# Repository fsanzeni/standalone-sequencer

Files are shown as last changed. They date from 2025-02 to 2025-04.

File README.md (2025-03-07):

# Standalone Super Sixteen Sequencer

This repository contains a hardware project built in KiCad—a reimagined and streamlined version of the [Super Sixteen project](https://github.com/matthewcieplak/super-sixteen). The goal is to create a standalone sequencer suitable for Eurorack and other synthesizer setups.

## Project Overview

The original Super Sixteen design has been reworked into a modular, three-board system:
- **7 Segment Display Board:** Manages visual output.
- **DAC and Mono Jack Board:** Provides digital-to-analog conversion and audio interfacing.
- **16-Step Keyboard Board:** Features 16 Cherry MX switches paired with reverse-mount RGB LEDs for step sequencing.

> All pins are broken out for flexible connectivity. The boards are designed to work together or independently based on your setup.

## Key Modifications

- **Simplified Design:** Removed the IO expander from the original Super Sixteen to reduce complexity.
- **Modular Approach:** Each board can function as part of a larger system or as a standalone unit.
- **Fabrication Update:** The PCBs are currently in fabrication. This project is a work in progress (WIP).

## Getting Started

1. **Hardware Designs:** Navigate to the appropriate subfolder in the `hardware` directory to access the KiCad schematic and PCB layout files. There are four subfolders in here: three correspond to the three PCBs (i.e., the "keyboard", the DAC and IO board, the 3-digit 7-segment display driver). The fourth folder contains the keyboard layout files I generated with the [Keyboard Layout Editor](https://www.keyboard-layout-editor.com/), which I imported into Kicad with the excellent [kicad-kbplacer](https://github.com/adamws/kicad-kbplacer) plugin. You can use the JSON file provided in this folder to variate the switches' layout without having to go through the hassle of moving things around precisely on Kicad :).
2. **Software Development:** The `software` folder is currently empty. Firmware or control software will be added as the project develops.
3. **Documentation:** Detailed build instructions, assembly guides, and design notes will be provided in the `documentation` folder over time.

## Hardware Design
As mentioned above, ths repo contains three PCBs:

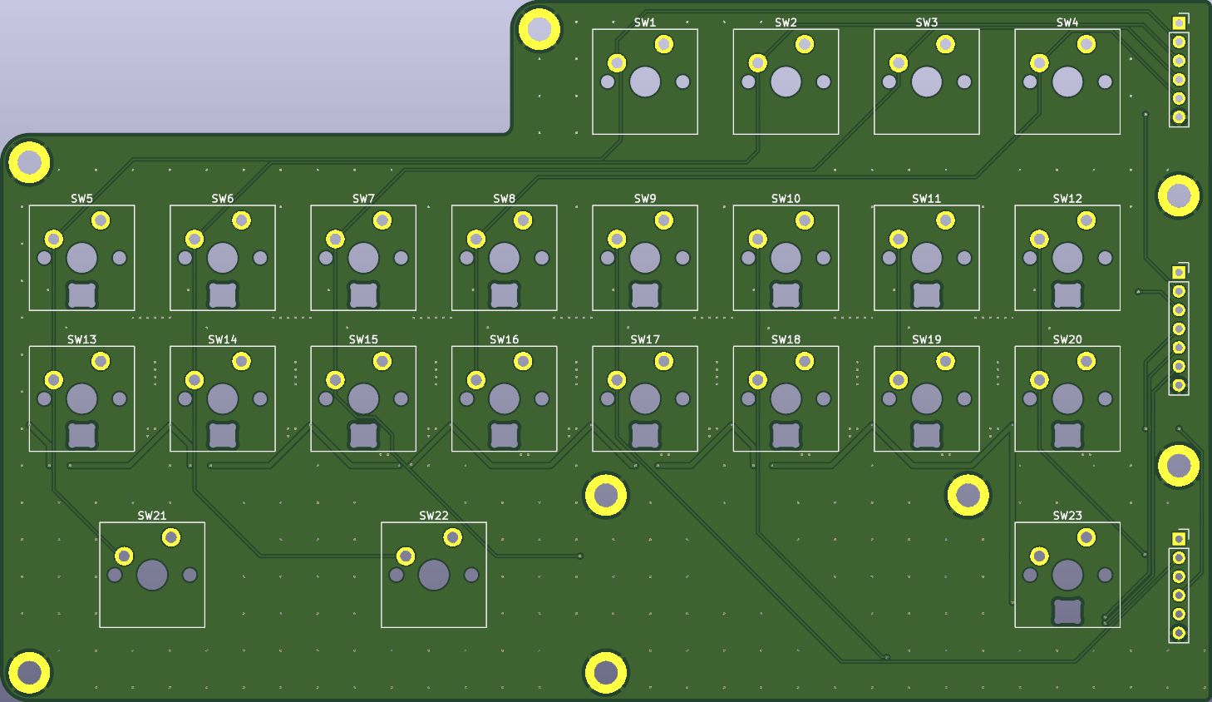
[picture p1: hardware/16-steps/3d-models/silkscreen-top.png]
16 steps pcb The keyboard PCB, with 16 steps and seven function buttons, all using Cherry MX keyswitches

_The keyboard PCB, with 16 steps and seven function buttons, all using Cherry MX keyswitches_

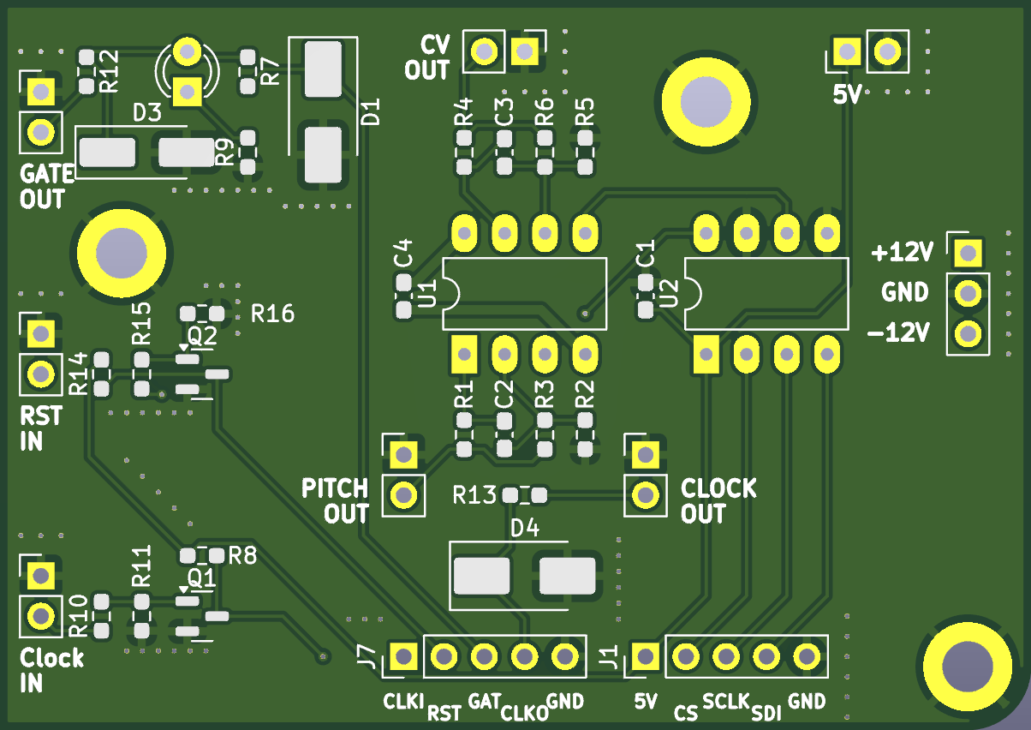
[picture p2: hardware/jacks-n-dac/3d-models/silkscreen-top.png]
DAC and Jacks pcb The DAC, opamp and IO board. I am using DIP packages for the two main ICs just because I had them laying around. The conversion to SMD packages is trivial - and there's plenty of space on the board!

_The DAC, opamp and IO board. I am using DIP packages for the two main ICs just because I had them laying around. The conversion to SMD packages is trivial - and there's plenty of space on the board!_

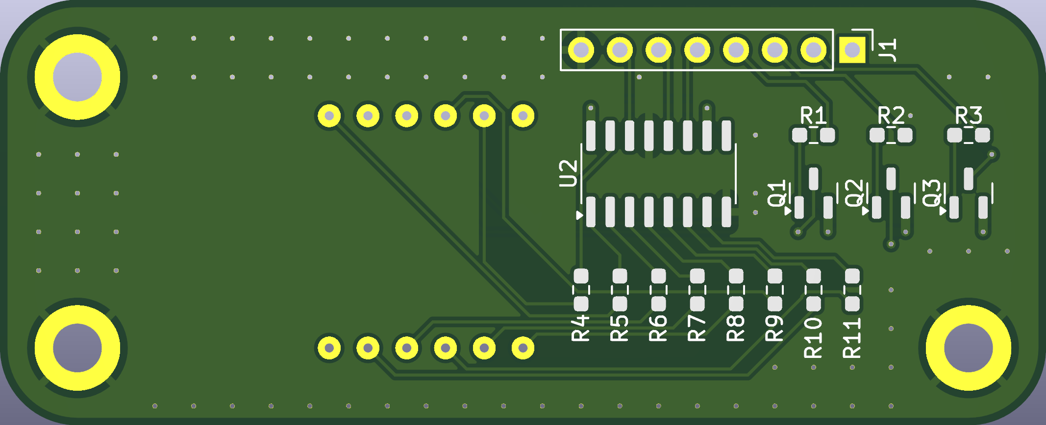
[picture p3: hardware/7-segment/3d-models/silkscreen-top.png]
7 Segment pcb The 7 segment driver pcb. I'm using a three-digit unit, 0.56in tall. Everything is driven by a 74HC595 to reduce the pins needed for interfacing with a microcontroller.

_The 7 segment driver pcb. I'm using a three-digit unit, 0.56" tall. Everything is driven by a 74HC595 to reduce the pins needed for interfacing with a microcontroller._

You will notice the glaring omission of a microcontroller from this setup. I am using the venerable Arduino MEGA as the brains of the operation, so that I have enough pins not to worry about faffing around with multiplexers and the like. 

## Inspiration

This project draws inspiration from the original [Super Sixteen project](https://github.com/matthewcieplak/super-sixteen). Visit their repository to learn more about the design and evolution of the sequencer.

## License

Code: GPL3.0 Hardware: cc-by-sa-3.0

## Contributing

Contributions, issues, and feature requests are welcome. Please feel free to open an issue or submit a pull request.

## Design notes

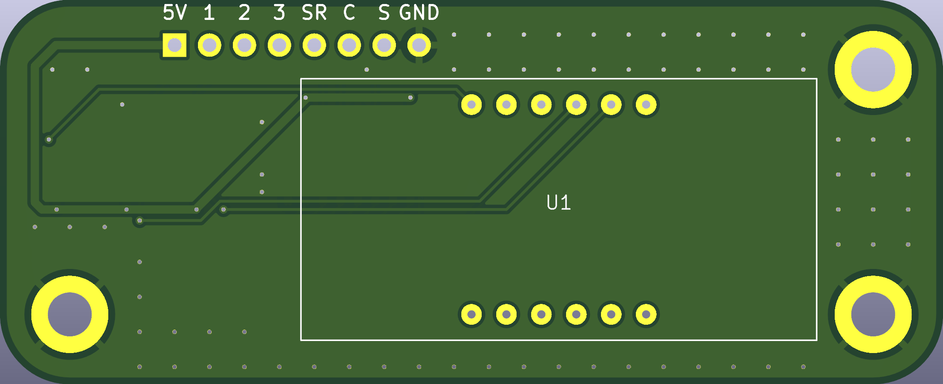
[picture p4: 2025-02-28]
hardware/7-segment/3d-models/silkscreen-bottom.png

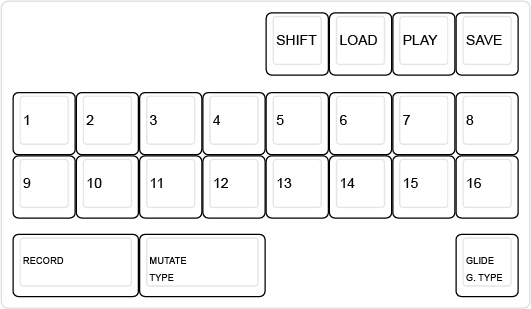
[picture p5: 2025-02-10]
hardware/switches layout/switches-layout.png

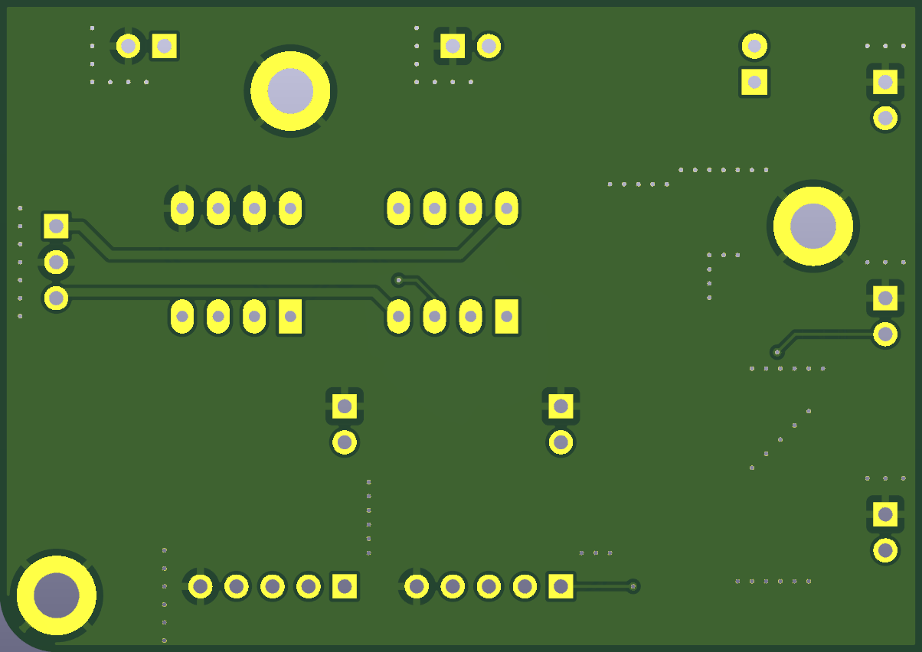
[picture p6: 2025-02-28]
hardware/jacks-n-dac/3d-models/silkscreen-bottom.png

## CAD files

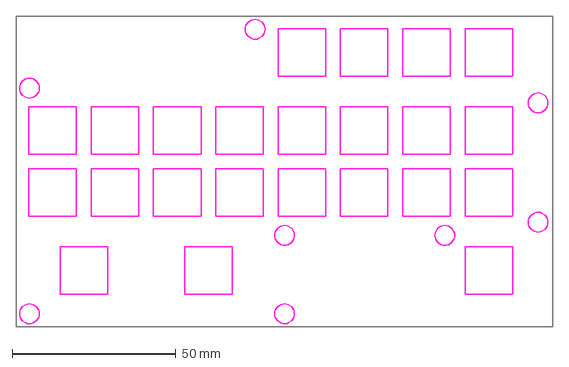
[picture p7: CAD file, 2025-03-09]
hardware/16-steps/16-steps-simplified-brd.dxf
164.0 x 95.0 mm

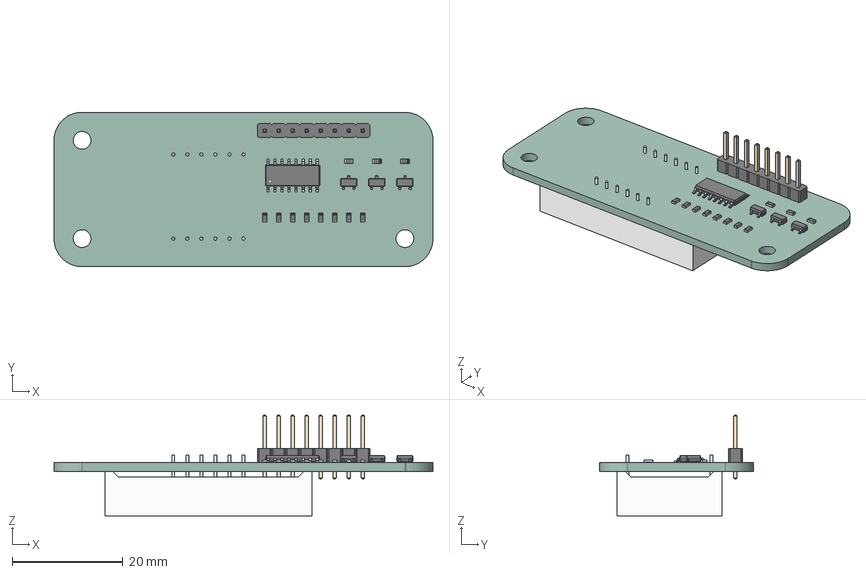
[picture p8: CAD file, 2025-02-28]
hardware/7-segment/3d-models/7-segment.step
68.6 x 27.9 x 18.2 mm
R_0603_1608Metric x 11
SOT_23 x 3
PinHeader_1x08_P254mm_Vertical
SOP-16_3.9x9.9mm_P1.27mm
(Unsaved)
7-segment_PCB

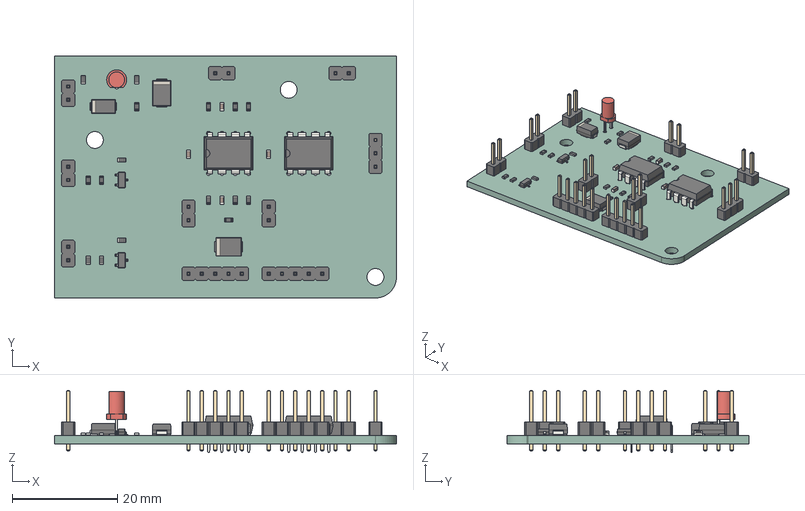
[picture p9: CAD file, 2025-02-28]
hardware/jacks-n-dac/3d-models/jacks-n-dac.step
65.0 x 46.0 x 11.8 mm
R_0603_1608Metric x 16
LED_D3.0mm_FlatTop
C_0603_1608Metric x 4
PinHeader_1x05_P254mm_Vertical x 2
DIP-8_W7.62mm x 2
PinHeader_1x02_P254mm_Vertical x 7
D_SMA
D_SMB x 2
PinHeader_1x03_P254mm_Vertical
SOT_23 x 2
jacks-n-dac_PCB

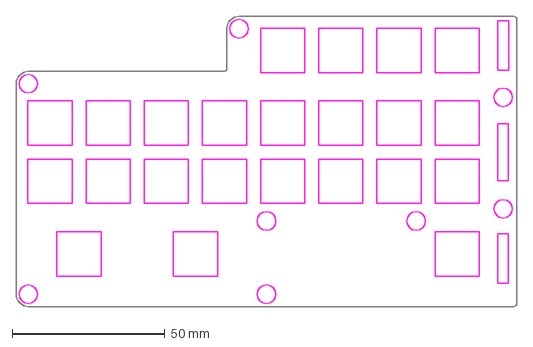
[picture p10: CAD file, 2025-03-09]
hardware/16-steps/16-steps-brd.dxf
164.0 x 95.0 mm

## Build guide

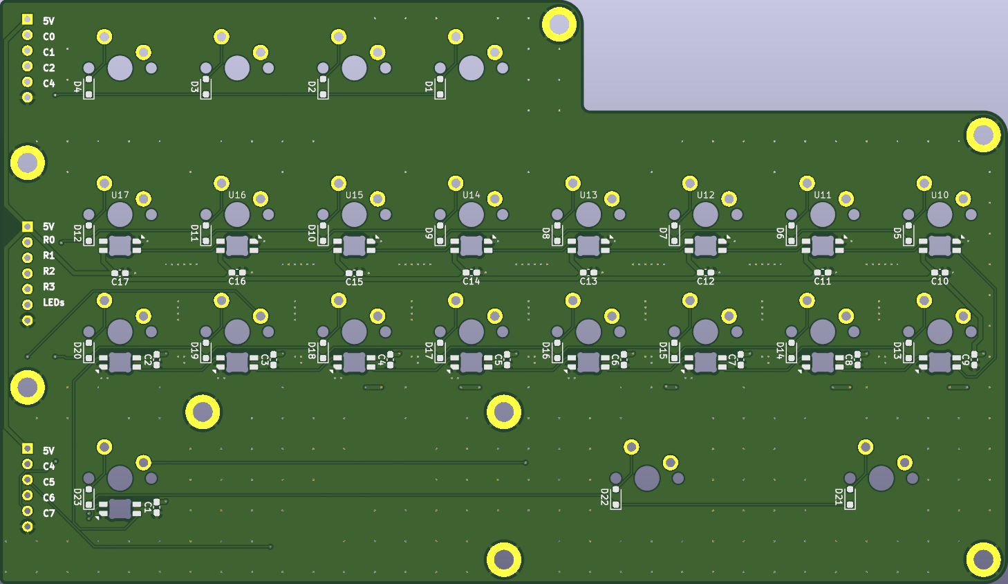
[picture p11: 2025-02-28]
hardware/16-steps/3d-models/silkscreen-bottom.png

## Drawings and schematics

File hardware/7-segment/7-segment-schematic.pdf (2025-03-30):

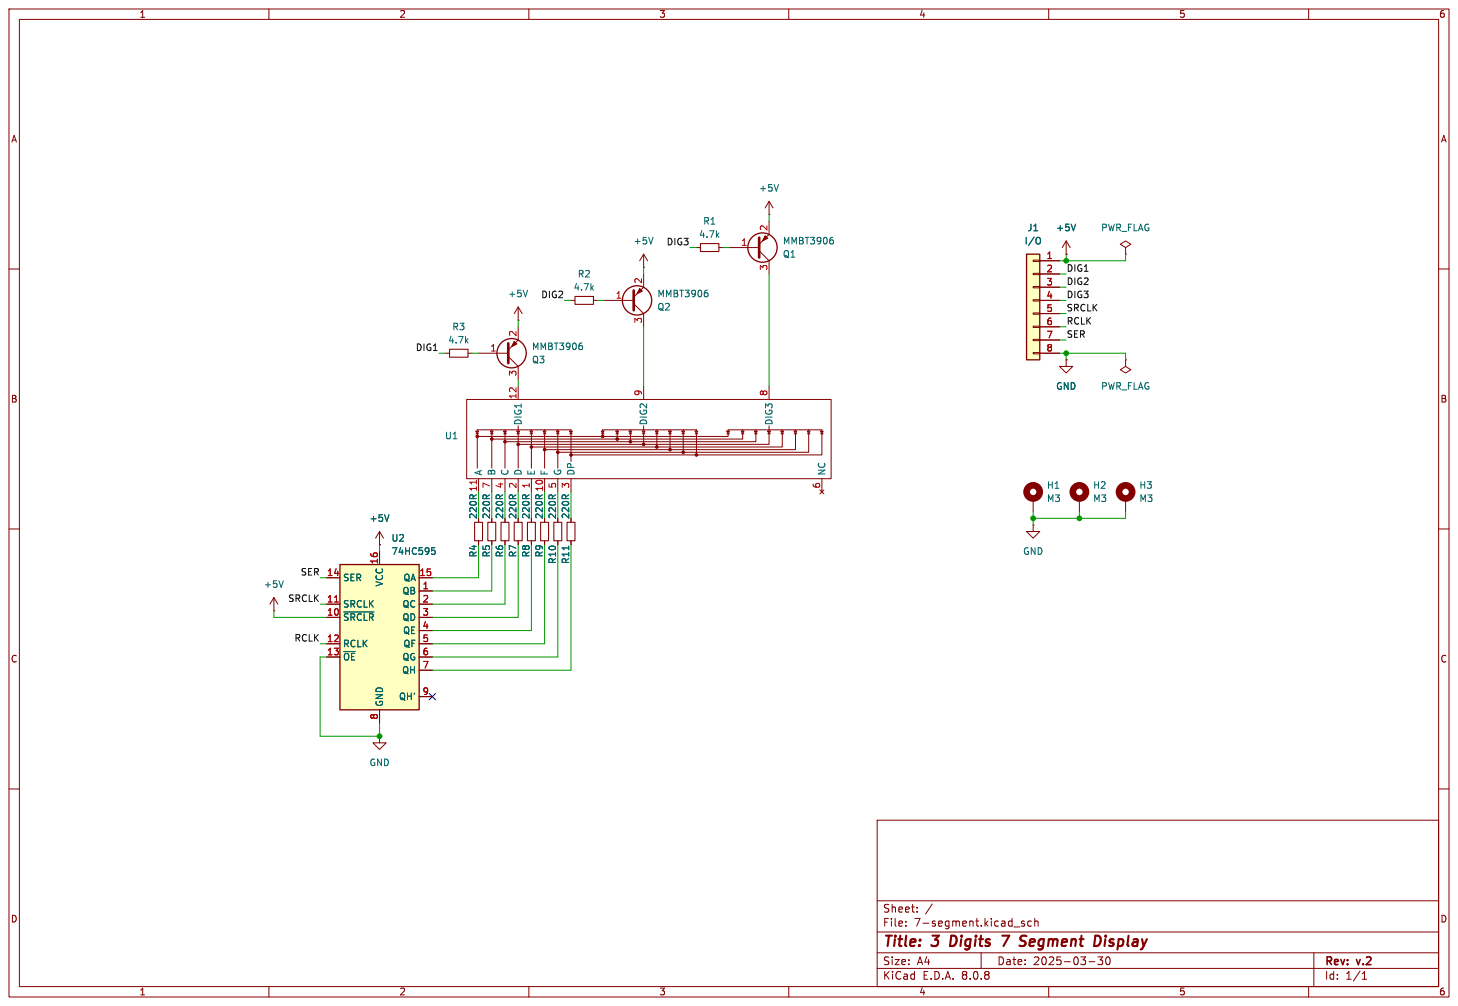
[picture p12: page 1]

9 U1 +5V R5 220R R11 220R R10 220R QB 1 ~{SRCLR} 10 SRCLK 11 RCLK 12 ~{OE} 13 SER 14 QA 15 VCC 16 QC 2 QD 3 QE 4 QF 5 QG 6 QH 7 GND

File: 7-segment.kicad_sch Sheet: /
Id: 1/1 Title: 3 Digits 7 Segment Display

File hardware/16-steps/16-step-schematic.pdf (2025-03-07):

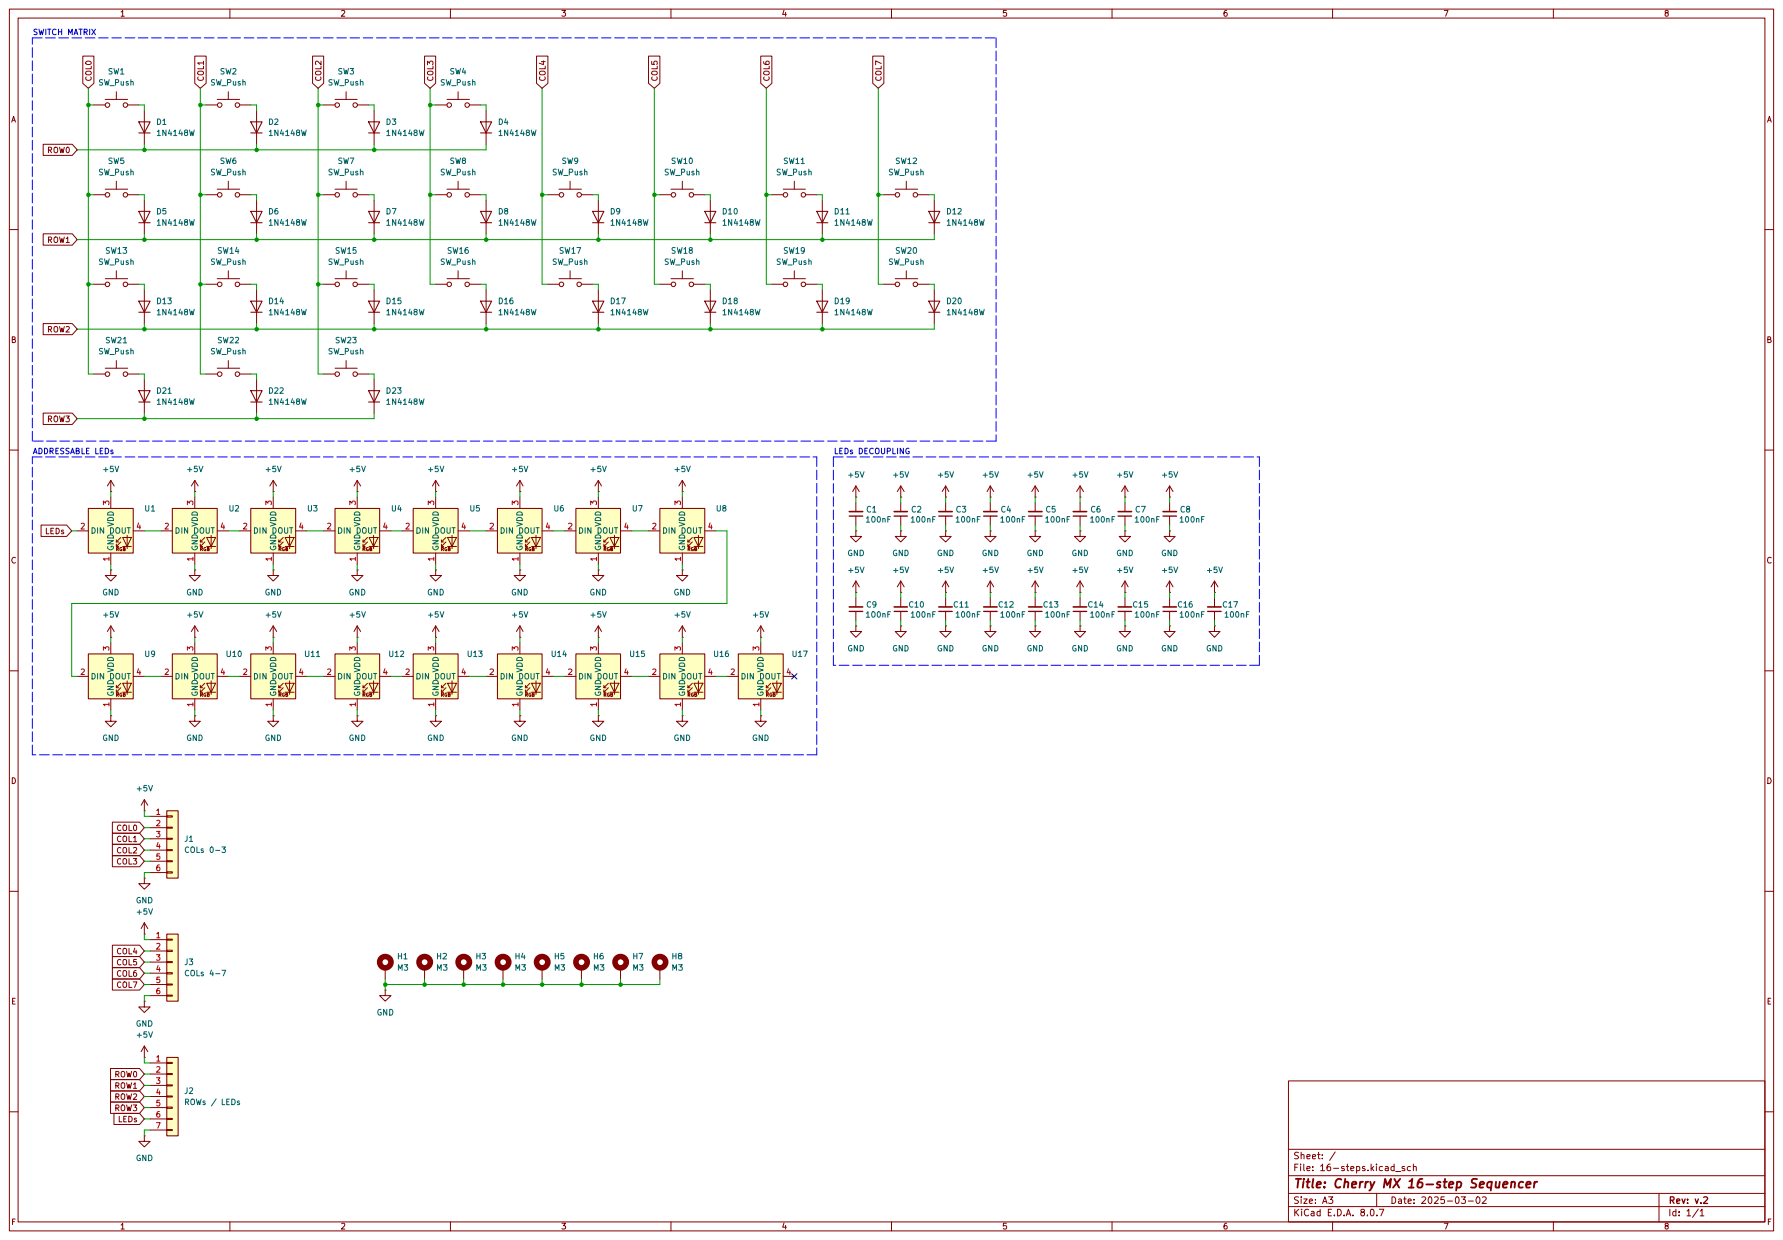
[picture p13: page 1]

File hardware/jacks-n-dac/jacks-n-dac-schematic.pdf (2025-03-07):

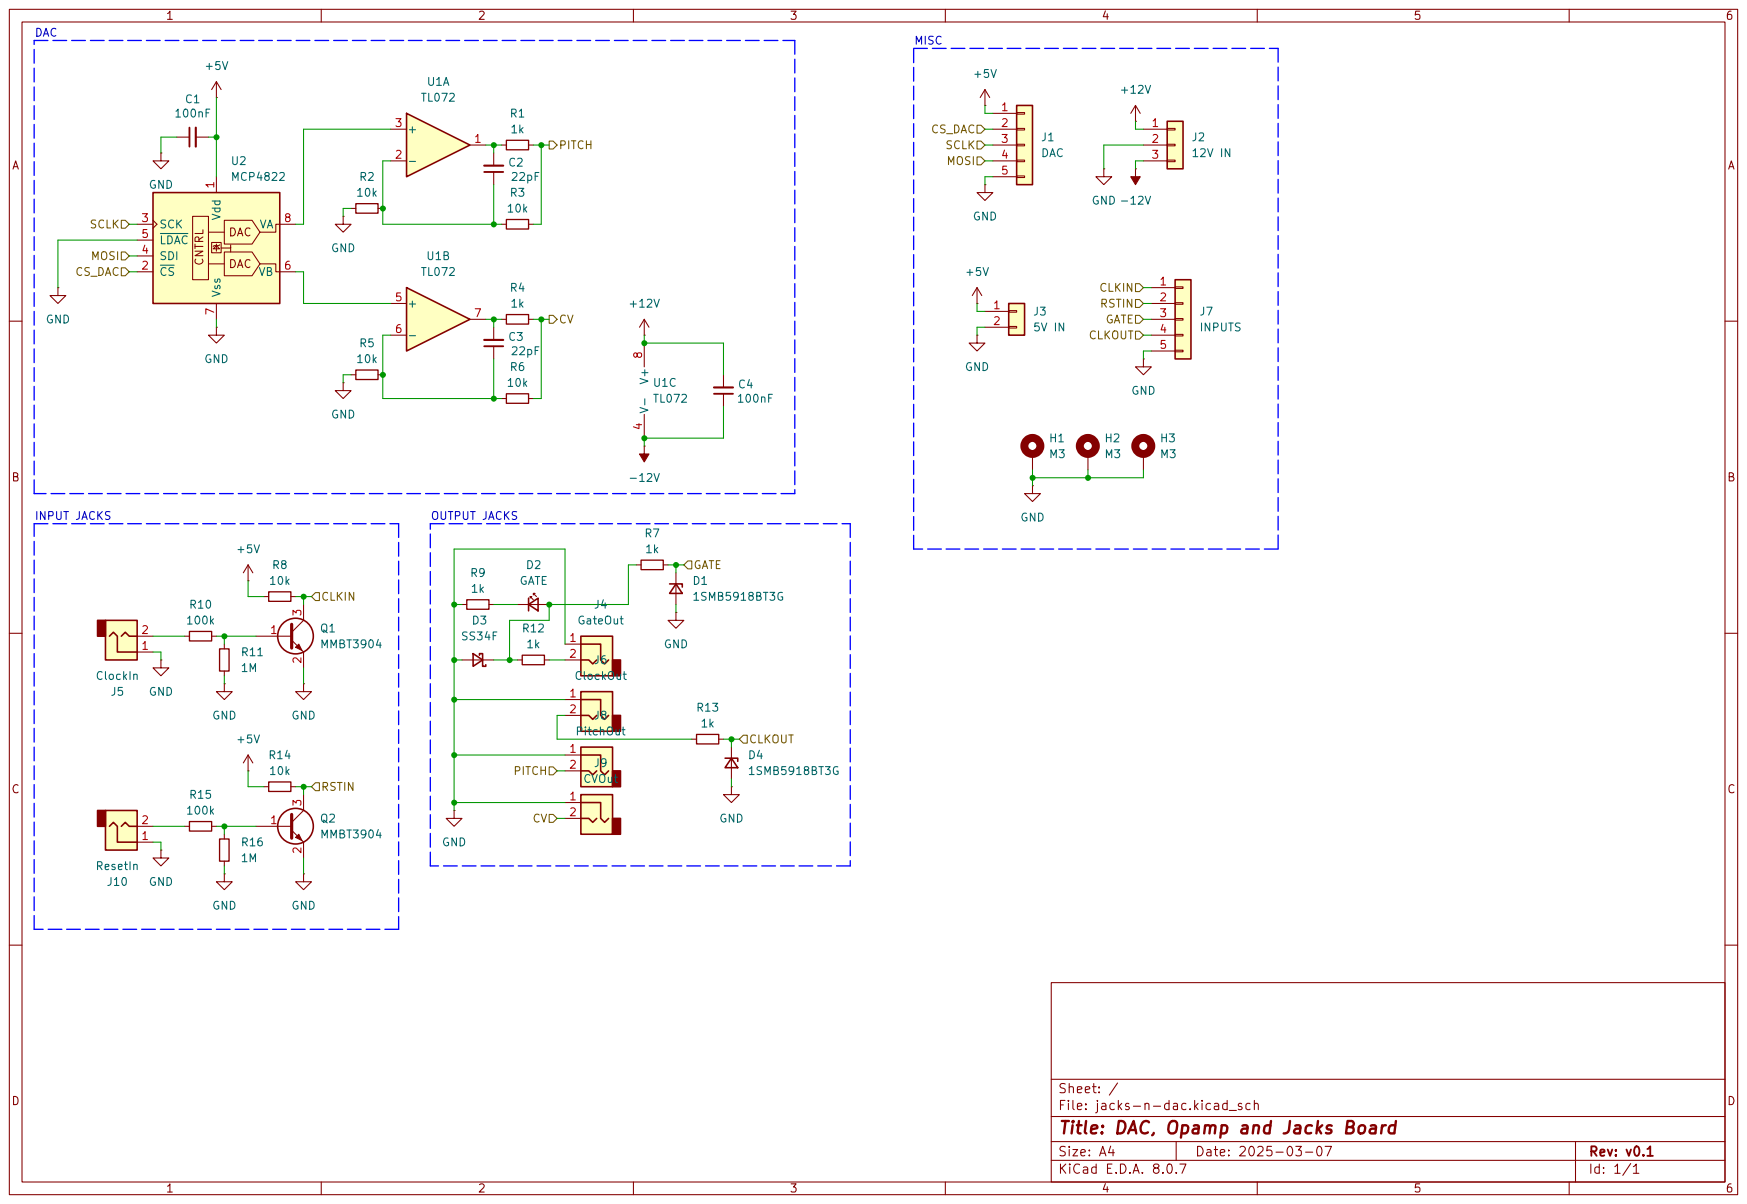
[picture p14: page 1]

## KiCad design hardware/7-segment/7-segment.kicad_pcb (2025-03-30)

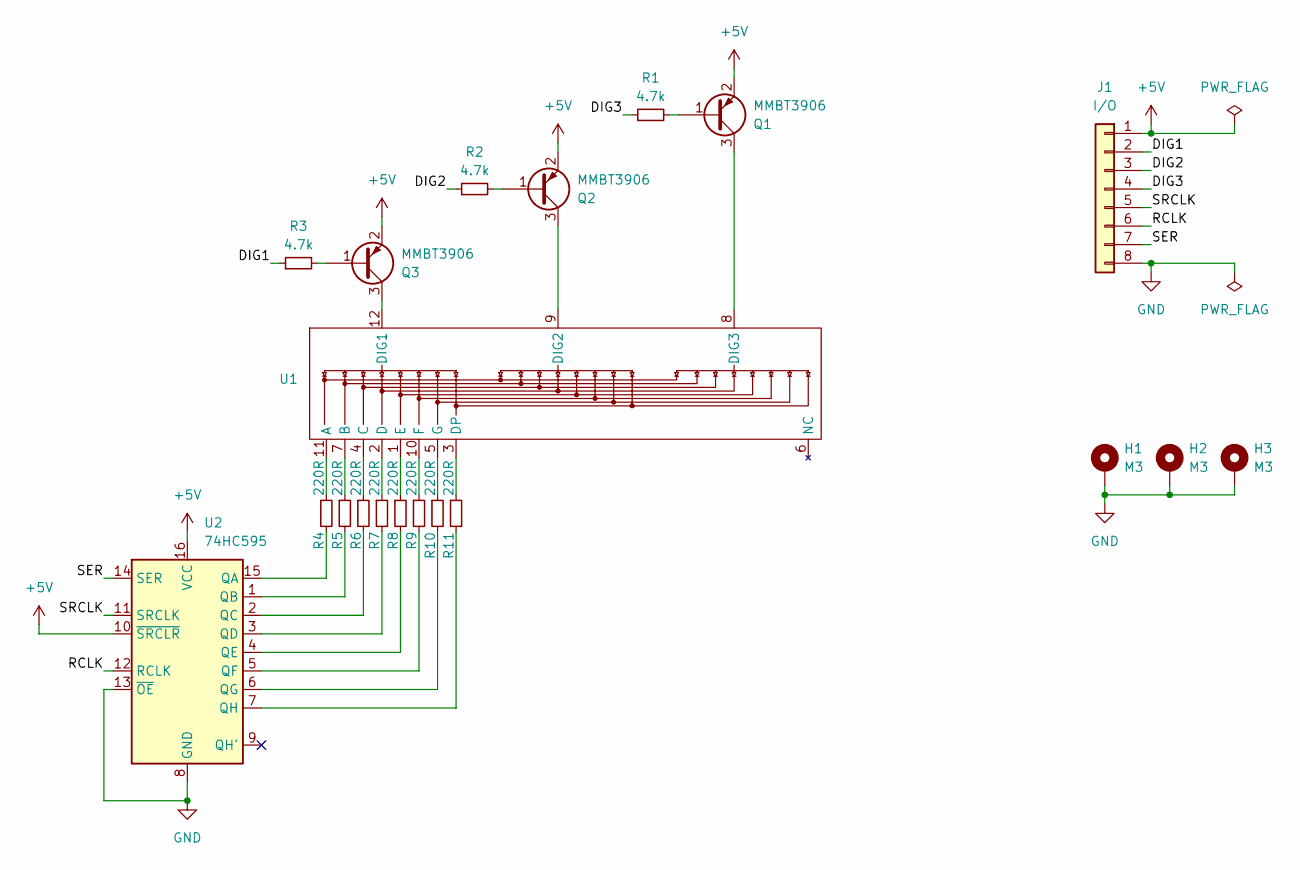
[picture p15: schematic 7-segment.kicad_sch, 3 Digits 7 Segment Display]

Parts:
H1, H2, H3: M3; MountingHole_3.2mm_M3_DIN965_Pad
J1: I/O; PinHeader_1x08_P2.54mm_Vertical
Q1, Q2, Q3: MMBT3906; SOT-23
R1, R2, R3: 4.7k; R_0603_1608Metric_Pad0.98x0.95mm_HandSolder
R4, R5, R6, R7, R8, R9, R10, R11: 220R; R_0603_1608Metric_Pad0.98x0.95mm_HandSolder
U1: FJ5361BH
U2: 74HC595; SOP-16_3.9x9.9mm_P1.27mm

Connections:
+5V: J1.1, Q1.2 (E), Q2.2 (E), Q3.2 (E), U2.10 (~SRCLR), U2.16 (VCC)
/DIG1: J1.2, R3.1
/DIG2: J1.3, R2.1
/DIG3: J1.4, R1.1
/RCLK: J1.6, U2.12 (RCLK)
/SER: J1.7, U2.14 (SER)
/SRCLK: J1.5, U2.11 (SRCLK)
GND: H1.1, H2.1, H3.1, J1.8, U2.8 (GND), U2.13 (~OE)
unnamed: Q1.1 (B), R1.2
unnamed: Q1.3 (C), U1.8 (DIG3)
unnamed: Q2.1 (B), R2.2
unnamed: Q2.3 (C), U1.9 (DIG2)
unnamed: Q3.1 (B), R3.2
unnamed: Q3.3 (C), U1.12 (DIG1)
unnamed: R4.1, U1.11 (A)
unnamed: R5.1, U1.7 (B)
unnamed: R6.1, U1.4 (C)
unnamed: R7.1, U1.2 (D)
unnamed: R11.1, U1.3 (DP)
unnamed: R8.1, U1.1 (E)
unnamed: R9.1, U1.10 (F)
unnamed: R10.1, U1.5 (G)
unnamed: R4.2, U2.15 (QA)
unnamed: R5.2, U2.1 (QB)
unnamed: R6.2, U2.2 (QC)
unnamed: R7.2, U2.3 (QD)
unnamed: R8.2, U2.4 (QE)
unnamed: R9.2, U2.5 (QF)
unnamed: R10.2, U2.6 (QG)
unnamed: R11.2, U2.7 (QH)

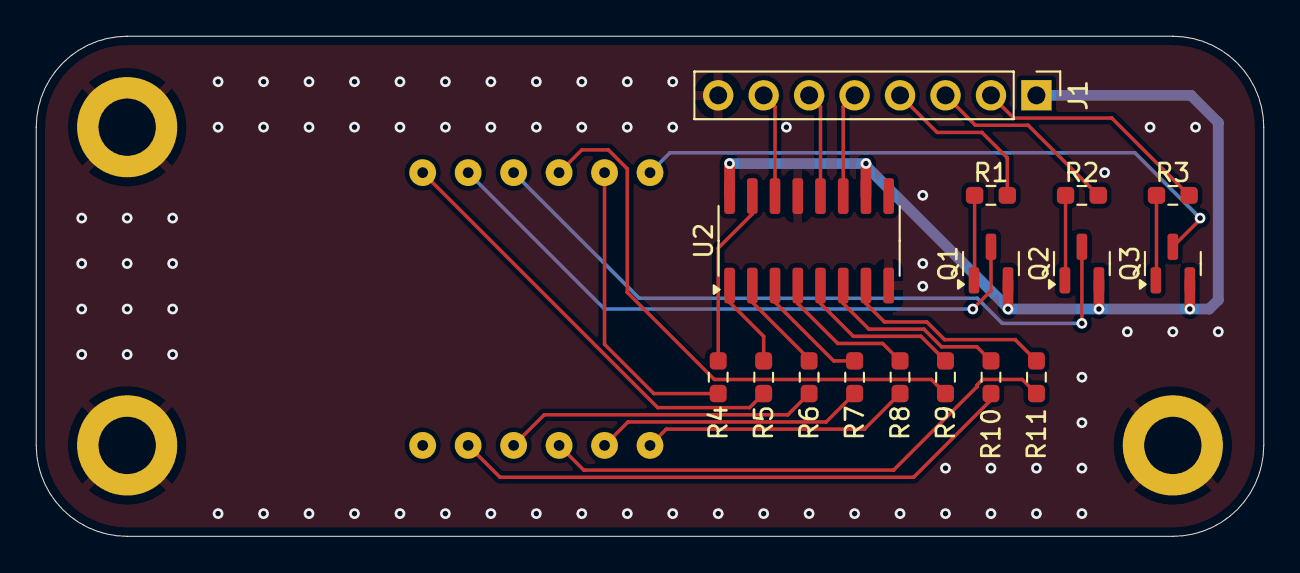
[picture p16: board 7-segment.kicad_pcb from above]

Board: 2 copper layers, 68.6 x 27.9 mm, 20 parts (1 on the bottom side), 30 nets.

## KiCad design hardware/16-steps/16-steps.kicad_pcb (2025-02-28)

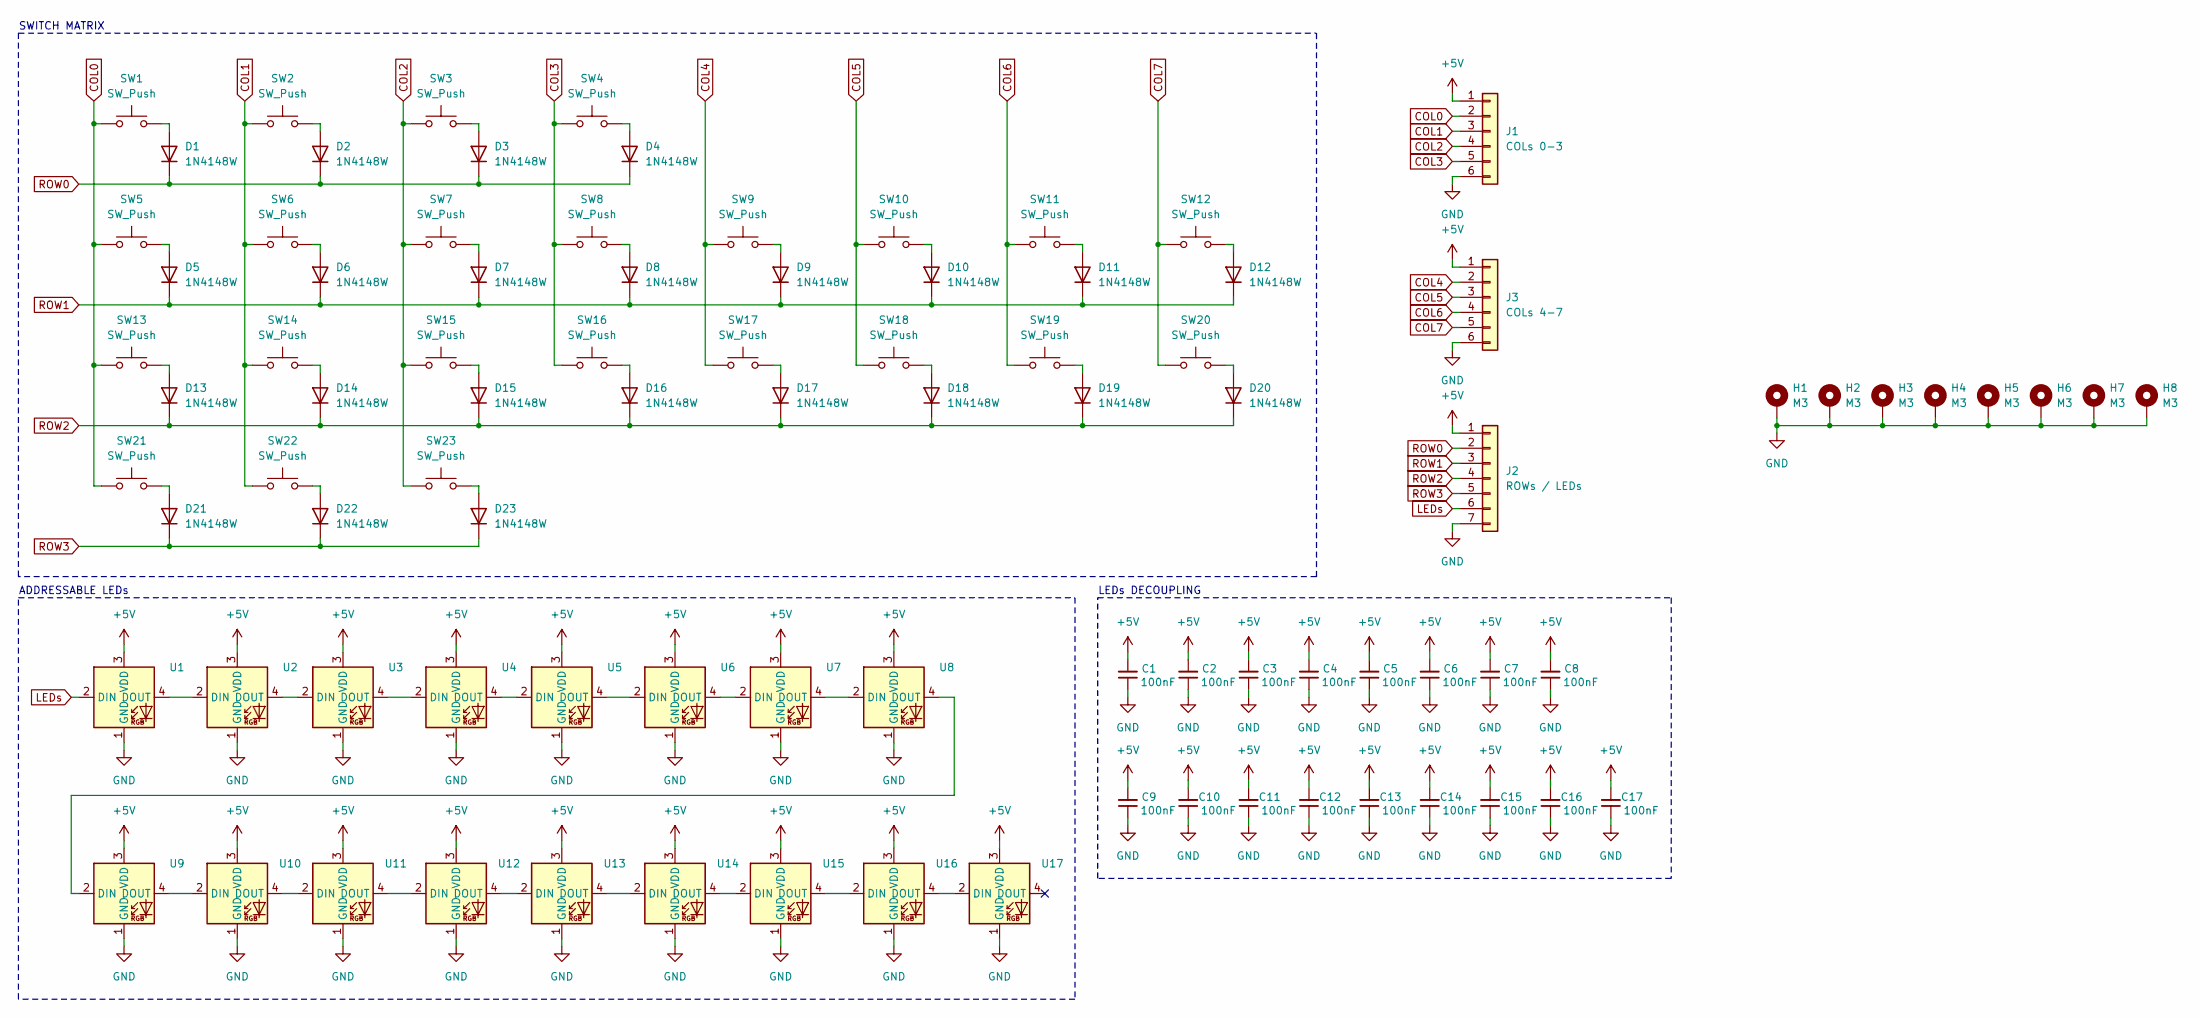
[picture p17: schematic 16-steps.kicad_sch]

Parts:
C1, C2, C3, C4, C5, C6, C7, C8, C9, C10, C11, C12, C13, C14, C15, C16, C17: 100nF; C_0603_1608Metric_Pad1.08x0.95mm_HandSolder
D1, D2, D3, D4, D5, D6, D7, D8, D9, D10, D11, D12, D13, D14, D15, D16, D17, D18, D19, D20, D21, D22, D23: 1N4148W; D_SOD-323_HandSoldering
H1, H2, H3, H4, H5, H6, H7, H8: M3; MountingHole_3.2mm_M3_DIN965_Pad
J1: COLs 0-3; PinSocket_1x06_P2.54mm_Vertical
J2: ROWs / LEDs; PinSocket_1x07_P2.54mm_Vertical
J3: COLs 4-7; PinSocket_1x06_P2.54mm_Vertical
SW1, SW2, SW3, SW4, SW5, SW6, SW7, SW8, SW9, SW10, SW11, SW12, SW13, SW14, SW15, SW16, SW17, SW18, SW19, SW20, SW23: SW_Push; SW_Cherry_MX_PCB_1.00u
SW21, SW22: SW_Push; SW_Cherry_MX_PCB_2.00u
U1, U2, U3, U4, U5, U6, U7, U8, U9: SK6812MINI-E-012
U10, U11, U12, U13, U14, U15, U16, U17: SK6812MINI-E-012-ROT

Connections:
+5V: C1.2, C2.2, C3.2, C4.2, C5.2, C6.2, C7.2, C8.2, C9.2, C10.2, C11.2, C12.2, C13.2, C14.2, C15.2, C16.2, C17.2, J1.1, J2.1, J3.1, U1.3 (VDD), U2.3 (VDD), U3.3 (VDD), U4.3 (VDD), U5.3 (VDD), U6.3 (VDD), U7.3 (VDD), U8.3 (VDD), U9.3 (VDD), U10.3 (VDD), U11.3 (VDD), U12.3 (VDD), U13.3 (VDD), U14.3 (VDD), U15.3 (VDD), U16.3 (VDD), U17.3 (VDD)
COL0: J1.2, SW1.1, SW5.1, SW13.1, SW21.1
COL1: J1.3, SW2.1, SW6.1, SW14.1, SW22.1
COL2: J1.4, SW3.1, SW7.1, SW15.1, SW23.1
COL3: J1.5, SW4.1, SW8.1, SW16.1
COL4: J3.2, SW9.1, SW17.1
COL5: J3.3, SW10.1, SW18.1
COL6: J3.4, SW11.1, SW19.1
COL7: J3.5, SW12.1, SW20.1
GND: C1.1, C2.1, C3.1, C4.1, C5.1, C6.1, C7.1, C8.1, C9.1, C10.1, C11.1, C12.1, C13.1, C14.1, C15.1, C16.1, C17.1, H1.1, H2.1, H3.1, H4.1, H5.1, H6.1, H7.1, H8.1, J1.6, J2.7, J3.6, U1.1 (GND), U2.1 (GND), U3.1 (GND), U4.1 (GND), U5.1 (GND), U6.1 (GND), U7.1 (GND), U8.1 (GND), U9.1 (GND), U10.1 (GND), U11.1 (GND), U12.1 (GND), U13.1 (GND), U14.1 (GND), U15.1 (GND), U16.1 (GND), U17.1 (GND)
LEDs: J2.6, U1.2 (DIN)
unnamed: D1.2 (A), SW1.2
unnamed: D2.2 (A), SW2.2
unnamed: D3.2 (A), SW3.2
unnamed: D4.2 (A), SW4.2
unnamed: D5.2 (A), SW5.2
unnamed: D6.2 (A), SW6.2
unnamed: D7.2 (A), SW7.2
unnamed: D8.2 (A), SW8.2
unnamed: D9.2 (A), SW9.2
unnamed: D10.2 (A), SW10.2
unnamed: D11.2 (A), SW11.2
unnamed: D12.2 (A), SW12.2
unnamed: D13.2 (A), SW13.2
unnamed: D14.2 (A), SW14.2
unnamed: D15.2 (A), SW15.2
unnamed: D16.2 (A), SW16.2
unnamed: D17.2 (A), SW17.2
unnamed: D18.2 (A), SW18.2
unnamed: D19.2 (A), SW19.2
unnamed: D20.2 (A), SW20.2
unnamed: D21.2 (A), SW21.2
unnamed: D22.2 (A), SW22.2
unnamed: D23.2 (A), SW23.2
unnamed: U1.4 (DOUT), U2.2 (DIN)
unnamed: U2.4 (DOUT), U3.2 (DIN)
unnamed: U3.4 (DOUT), U4.2 (DIN)
unnamed: U4.4 (DOUT), U5.2 (DIN)
unnamed: U5.4 (DOUT), U6.2 (DIN)
unnamed: U6.4 (DOUT), U7.2 (DIN)
unnamed: U7.4 (DOUT), U8.2 (DIN)
unnamed: U8.4 (DOUT), U9.2 (DIN)
unnamed: U9.4 (DOUT), U10.2 (DIN)
unnamed: U10.4 (DOUT), U11.2 (DIN)
unnamed: U11.4 (DOUT), U12.2 (DIN)
unnamed: U12.4 (DOUT), U13.2 (DIN)
unnamed: U13.4 (DOUT), U14.2 (DIN)
unnamed: U14.4 (DOUT), U15.2 (DIN)
unnamed: U15.4 (DOUT), U16.2 (DIN)
unnamed: U16.4 (DOUT), U17.2 (DIN)
ROW0: D1.1 (K), D2.1 (K), D3.1 (K), D4.1 (K), J2.2
ROW1: D5.1 (K), D6.1 (K), D7.1 (K), D8.1 (K), D9.1 (K), D10.1 (K), D11.1 (K), D12.1 (K), J2.3
ROW2: D13.1 (K), D14.1 (K), D15.1 (K), D16.1 (K), D17.1 (K), D18.1 (K), D19.1 (K), D20.1 (K), J2.4
ROW3: D21.1 (K), D22.1 (K), D23.1 (K), J2.5

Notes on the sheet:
SWITCH MATRIX
LEDs DECOUPLING
ADDRESSABLE LEDs

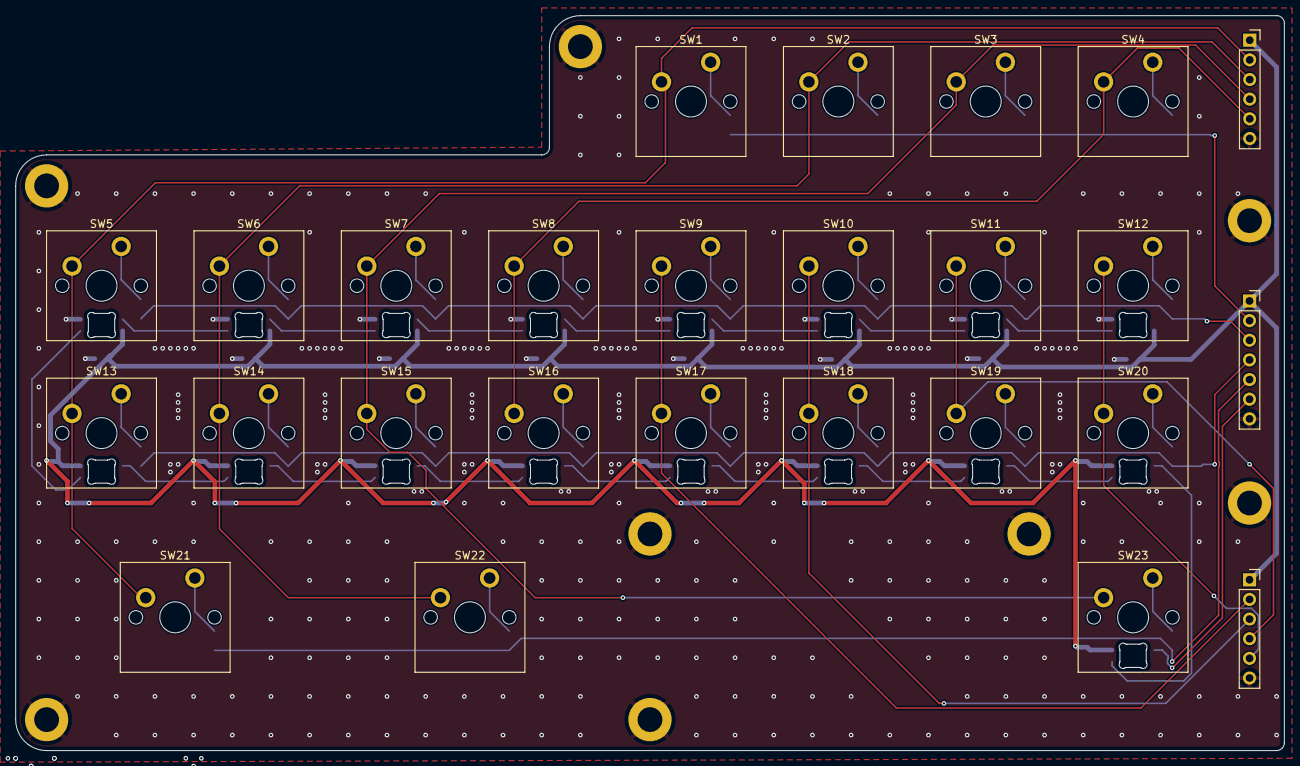
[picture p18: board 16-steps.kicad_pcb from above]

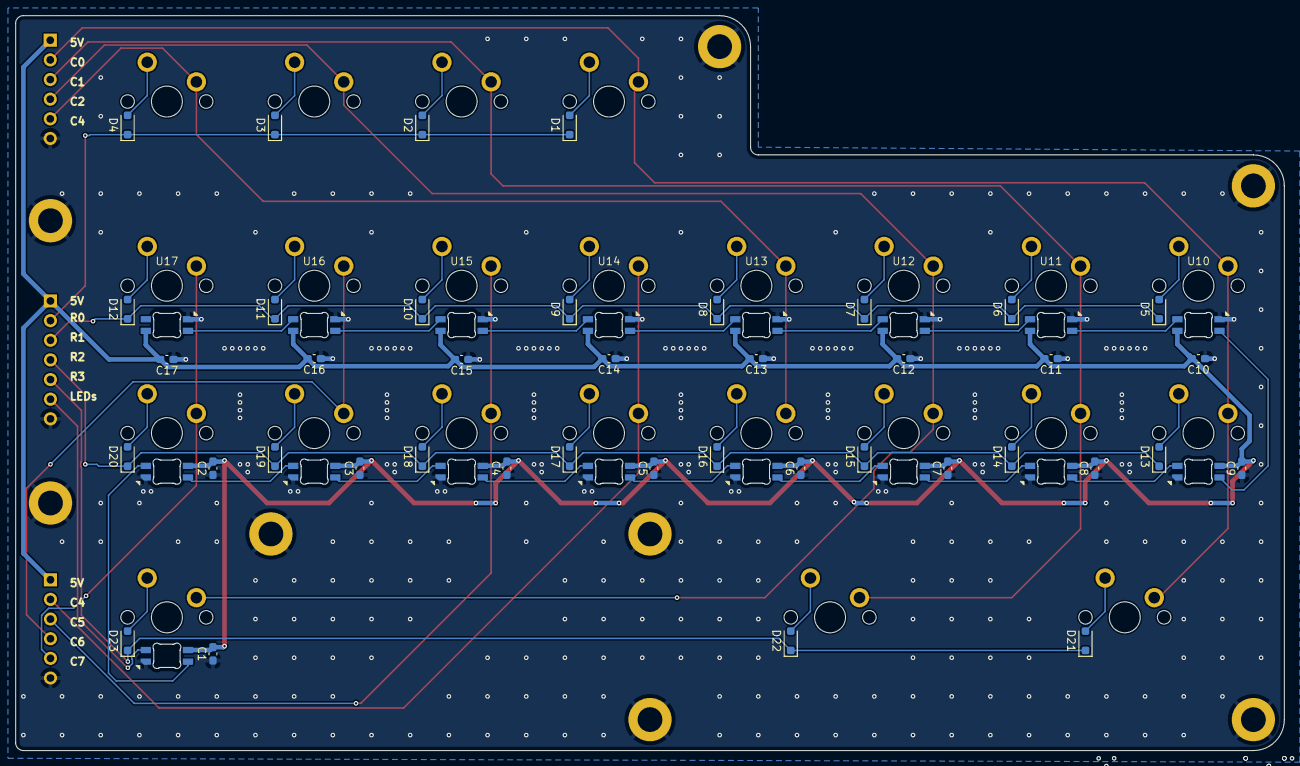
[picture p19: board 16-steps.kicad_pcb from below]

Board: 2 copper layers, 164.0 x 95.0 mm, 91 parts (57 on the bottom side), 54 nets.

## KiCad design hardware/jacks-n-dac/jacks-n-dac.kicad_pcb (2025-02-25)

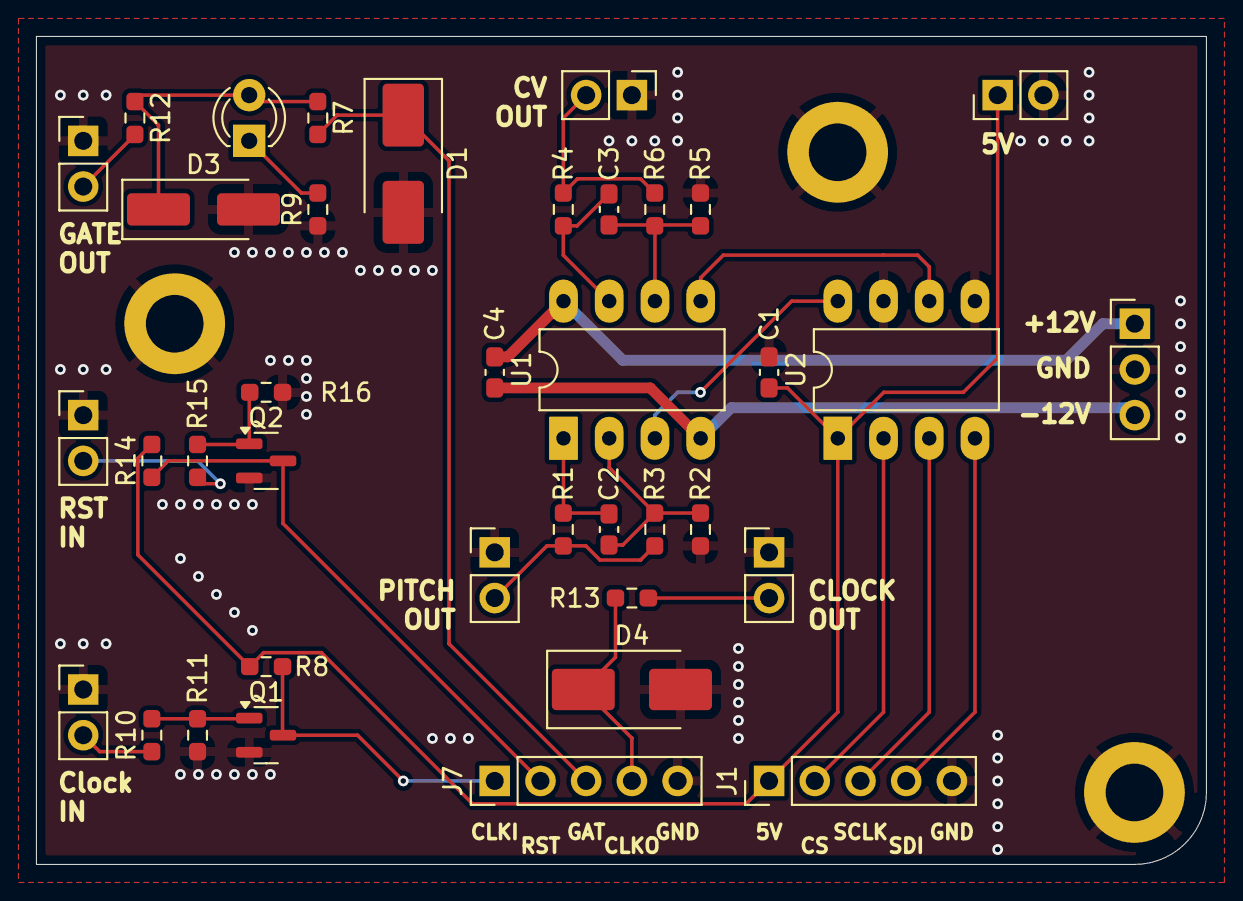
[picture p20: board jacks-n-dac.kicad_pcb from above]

Board: 2 copper layers, 65.0 x 46.0 mm, 41 parts (0 on the bottom side), 27 nets.

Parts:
C1, C4: 100nF; C_0603_1608Metric_Pad1.08x0.95mm_HandSolder
C2, C3: 22pF; C_0603_1608Metric_Pad1.08x0.95mm_HandSolder
D1, D4: 1SMB5918BT3G; D_SMB_Handsoldering
D2: GATE; LED_D3.0mm_FlatTop
D3: SS34F; D_SMA_Handsoldering
H1, H2, H3: M3; MountingHole_3.2mm_M3_DIN965_Pad
J1: DAC; PinHeader_1x05_P2.54mm_Vertical
J2: 12V IN; PinHeader_1x03_P2.54mm_Vertical
J3: 5V IN; PinHeader_1x02_P2.54mm_Vertical
J4: GateOut; PinHeader_1x02_P2.54mm_Vertical
J5: ClockIn; PinHeader_1x02_P2.54mm_Vertical
J6: ClockOut; PinHeader_1x02_P2.54mm_Vertical
J7: INPUTS; PinHeader_1x05_P2.54mm_Vertical
J8: PitchOut; PinHeader_1x02_P2.54mm_Vertical
J9: CVOut; PinHeader_1x02_P2.54mm_Vertical
J10: ResetIn; PinHeader_1x02_P2.54mm_Vertical
Q1, Q2: MMBT3904; SOT-23
R1, R4, R7, R9, R12, R13: 1k; R_0603_1608Metric_Pad0.98x0.95mm_HandSolder
R2, R3, R5, R6, R8, R14: 10k; R_0603_1608Metric_Pad0.98x0.95mm_HandSolder
R10, R15: 100k; R_0603_1608Metric_Pad0.98x0.95mm_HandSolder
R11, R16: 1M; R_0603_1608Metric_Pad0.98x0.95mm_HandSolder
U1: TL072; DIP-8_W7.62mm_LongPads
U2: MCP4822; DIP-8_W7.62mm_LongPads

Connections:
+5V: C1.2, J1.1, J3.1, R8.2, R14.2, U2.1 (Vdd)
+12V: C4.2, J2.1, U1.8 (V+)
-12V: C4.1, J2.3, U1.4 (V-)
/CLKIN: J7.1, Q1.3 (C), R8.1
/CLKOUT: D4.1 (K), J7.4, R13.2
/CS_DAC: J1.2, U2.2 (~CS)
/CV: J9.2, R4.2, R6.2
/GATE: D1.1 (K), J7.3, R7.2
/MOSI: J1.4, U2.4 (SDI)
/PITCH: J8.2, R1.2, R3.2
/RSTIN: J7.2, Q2.3 (C), R14.1
/SCLK: J1.3, U2.3 (SCK)
GND: C1.1, D1.2 (A), D3.2 (A), D4.2 (A), H1.1, H2.1, H3.1, J1.5, J2.2, J3.2, J4.1, J5.1, J6.1, J7.5, J8.1, J9.1, J10.1, Q1.2 (E), Q2.2 (E), R2.1, R5.1, R9.1, R11.1, R16.1, U2.5 (~LDAC), U2.7 (Vss)
unnamed: C2.2, R1.1, U1.1
unnamed: C3.2, R4.1, U1.7
unnamed: D2.2 (A), D3.1 (K), R7.1, R12.1
unnamed: D2.1 (K), R9.2
unnamed: J4.2, R12.2
unnamed: J5.2, R10.1
unnamed: J6.2, R13.1
unnamed: J10.2, R15.1
unnamed: Q1.1 (B), R10.2, R11.2
unnamed: Q2.1 (B), R15.2, R16.2
unnamed: U1.3 (+), U2.8 (VA)
unnamed: C2.1, R2.2, R3.1, U1.2 (-)
unnamed: U1.5 (+), U2.6 (VB)
unnamed: C3.1, R5.2, R6.1, U1.6 (-)

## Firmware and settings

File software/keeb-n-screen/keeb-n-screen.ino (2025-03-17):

#include <Keypad.h>
#include <Adafruit_NeoPixel.h>
#include <elapsedMillis.h>

// Pin Definitions
const byte dataPin = 21;   // SER (pin 14) of 74HC595
const byte clockPin = 19;  // SRCLK (pin 11) of 74HC595
const byte latchPin = 20;  // RCLK (pin 12) of 74HC595

const byte digit1Pin = 16;  // Common anode for digit 1
const byte digit2Pin = 17;  // Common anode for digit 2
const byte digit3Pin = 18;  // Common anode for digit 3

byte currentDisplayDigits[3] = {10, 10, 10}; // Start with all off
byte currentDigit = 0;
unsigned long previousTime = 0;
const unsigned long refreshInterval = 2; // Milliseconds per digit

const byte LED_PIN = 6;  // LED pin, most are valid

// Define the number of rows and columns
const byte ROWS = 4;
const byte COLS = 8;

byte rowPins[ROWS] = { 46, 48, 50, 52 };                  // Connect to the row pinouts of the keypad
byte colPins[COLS] = { 39, 41, 43, 45, 47, 49, 51, 53 };  // Connect to the column pinouts of the keypad

// Define number of LEDs
const byte LED_COUNT = 17;

// Declare NeoPixel object:
Adafruit_NeoPixel strip(LED_COUNT, LED_PIN, NEO_GRB + NEO_KHZ800);

// Define a keymap
char keys[ROWS][COLS] = {
  { '1', '2', '3', 'A', 'B', 'C', 'D', 'E' },
  { '4', '5', '6', 'F', 'G', 'H', 'I', 'J' },
  { '7', '8', '9', 'K', 'L', 'M', 'N', 'O' },
  { '*', '0', '#', 'P', 'Q', 'R', 'S', 'T' }
};

// Keypad object
Keypad keypad = Keypad(makeKeymap(keys), rowPins, colPins, ROWS, COLS);

// Segment patterns for 0-9 (the first number controls the decimal point: 1 - OFF, 0 - ON)
byte sevenSegDigits[11] = {
  0b11000000,  // 0
  0b11111001,  // 1
  0b10100100,  // 2
  0b10110000,  // 3
  0b10011001,  // 4
  0b10010010,  // 5
  0b10000010,  // 6
  0b11111000,  // 7
  0b10000000,  // 8
  0b10010000,  // 9
  0b11111111   // off
};

void setup() {
  screenSetup();
  //LEDsSetup(50);  // Argument: Max Brightness, number between 0 and 255
  currentDisplayDigits[0] = 2; // Digit 1 = 0
  currentDisplayDigits[1] = 1; // Digit 2 = off
  currentDisplayDigits[2] = 5; // Digit 3 = off
}

void loop() {
  //readKeyPress();
  //updateDisplay(); // Update the display continuously
}

void screenSetup() {
  pinMode(dataPin, OUTPUT);
  pinMode(clockPin, OUTPUT);
  pinMode(latchPin, OUTPUT);
  pinMode(digit1Pin, OUTPUT);
  pinMode(digit2Pin, OUTPUT);
  pinMode(digit3Pin, OUTPUT);

  // Initialise all digits off
  digitalWrite(digit1Pin, LOW);
  digitalWrite(digit2Pin, LOW);
  digitalWrite(digit3Pin, LOW);
}

void LEDsSetup(byte maxBrightness) {
  strip.begin();
  strip.show();
  strip.setBrightness(maxBrightness);
}

void updateDisplay() {
  if (millis() - previousTime >= refreshInterval) {
    previousTime = millis();

    // Turn off all digits
    digitalWrite(digit1Pin, LOW);
    digitalWrite(digit2Pin, LOW);
    digitalWrite(digit3Pin, LOW);

    // Send data for the CURRENT digit
    digitalWrite(latchPin, LOW);
    shiftOut(dataPin, clockPin, MSBFIRST, sevenSegDigits[currentDisplayDigits[currentDigit]]); // Use MSB or LSB
    digitalWrite(latchPin, HIGH);

    // Activate the current digit
    switch (currentDigit) {
      case 0: digitalWrite(digit1Pin, HIGH); break;
      case 1: digitalWrite(digit2Pin, HIGH); break;
      case 2: digitalWrite(digit3Pin, HIGH); break;
    }

    currentDigit = (currentDigit + 1) % 3; // Cycle through digits
  }
}

void readKeyPress() {
  // Read the pressed key
  char key = keypad.getKey();

  if (key != NO_KEY) {  // A valid key press is detected
    if (key == '1') {
      // SHIFT

    } else if (key == '2') {
      // PLAY

    } else if (key == '3') {
      // LOAD

    } else if (key == 'A') {
      // SAVE

    } else if (key == '4') {
      // STEP 1
      currentDisplayDigits[0] = 0;
      currentDisplayDigits[1] = 0;
      currentDisplayDigits[2] = 1;
    } else if (key == '5') {
      // STEP 2
      byte newDigits[3] = {10, 10, 2};
      memcpy(currentDisplayDigits, newDigits, sizeof(newDigits));
    } else if (key == '6') {
      // STEP 3

    } else if (key == 'F') {
      // STEP 4

    } else if (key == 'G') {
      // STEP 5

    } else if (key == 'H') {
      // STEP 6

    } else if (key == 'I') {
      // STEP 7

    } else if (key == 'J') {
      // STEP 8

    } else if (key == '7') {
      // STEP 9

    } else if (key == '8') {
      // STEP 10

    } else if (key == '9') {
      // STEP 11

    } else if (key == 'K') {
      // STEP 12

    } else if (key == 'L') {
      // STEP 13

    } else if (key == 'M') {
      // STEP 14

    } else if (key == 'N') {
      // STEP 15

    } else if (key == 'O') {
      // STEP 16

    } else if (key == '*') {
      // RECORD

    } else if (key == '0') {
      // MUTATE

    } else if (key == '#') {
      // GLIDE
    } else {
      // ERROR OF SOME SORT
    }
  }
}

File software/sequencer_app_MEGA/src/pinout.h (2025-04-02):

#pragma once

// MISC PINS
#define GATE_PIN                9
//#define LDAC_PIN 1
#define CLOCK_OUT_PIN           53
#define CLOCK_IN_PIN            52
#define RESET_PIN               10

// KEYBOARD PINS
#define ROW0_PIN                38
#define ROW1_PIN                40
#define ROW2_PIN                42
#define ROW3_PIN                44

#define COL0_PIN                31
#define COL1_PIN                33
#define COL2_PIN                35
#define COL3_PIN                37
#define COL4_PIN                39
#define COL5_PIN                41
#define COL6_PIN                43
#define COL7_PIN                45

const int buttonRows[4] = { ROW0_PIN, ROW1_PIN, ROW2_PIN, ROW3_PIN };
const int buttonCols[8] = { COL0_PIN, COL1_PIN, COL2_PIN, COL3_PIN,
                            COL4_PIN, COL5_PIN, COL6_PIN, COL7_PIN };

// LED PINS
#define GLIDE_NEOPIXEL_PIN      23
#define LED_MATRIX_PIN          2

// TODO
// #define GLIDE_LED_PIN 15 //these 8 are on the button driver chip, not the MCU
#define GLIDE_PIN               14
#define REPEAT_PIN              13
#define RECORD_PIN              12
#define SAVE_PIN                11 
#define LOAD_PIN                10 
#define PLAY_PIN                9 
#define SHIFT_PIN               8

// TODO - CHIP SELECT PINS
// #define CS0_PIN  10 //MCP23S17 for buttons, aux LEDS
// #define CS1_PIN  9  //Display/matrix shift registers
#define CSFLASH_PIN             4  //Flash memory


// DIGIT DISPLAY PINS
#define DIGIT_1_PIN             16
#define DIGIT_2_PIN             17
#define DIGIT_3_PIN             18
#define DIO_PIN                 21
#define RCLK_PIN                20
#define SCLK_PIN                19

// DAC PINS
#define CSDAC_PIN               7
#define DAC_DATA_PIN            5
#define DAC_CLOCK_PIN           6

// POTENTIOMETER PINS - TODO
#define ANALOG_PIN_1            A0
#define ANALOG_PIN_2            A1
#define ANALOG_PIN_3            A2
#define ANALOG_PIN_4            A3

// ENCODER PINS
#define ENC_A_PIN               A4
#define ENC_B_PIN               A5
#define ENC_PORT                PINC

// GAIN
#define GAIN_1                  0x1
#define GAIN_2                  0x0

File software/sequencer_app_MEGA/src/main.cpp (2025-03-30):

// Copyright 2019 Extralife Instruments.
//
// Author: Matthew Cieplak (extralifedisco@gmail.com)
// Ported: fsan
//
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
// See http://creativecommons.org/licenses/MIT/ for more information.
//
// -----------------------------------------------------------------------------
//
// User interface.

#include <Arduino.h>
#include <string.h>
#include <SPI.h>
#include <elapsedMillis.h>

#include "Buttons.h"
#include "Encoder.h"
#include "AnalogIO.h"
#include "Dac.h"
#include "Display.h"
#include "Font.h"
#include "LEDMatrix.h"
#include "Main.h"
#include "Sequencer.h"
#include "Ui.h"
#include "Dac.h"
#include "Calibrate.h"
#include "Pinout.h"

Ui ui;
Dac dac;
Calibration calibration;
Sequencer sequencer;
Display disp;

void setup() {
	analogReference(EXTERNAL); // use AREF for reference voltage

	calibration.readCalibrationValues(); // -- disable to bypass overwriting EEPROM during programming/development. uncomment for typical use
	
    sequencer.init(calibration, dac);
	ui.init(calibration, dac, sequencer);
//   disp.init();

}


void loop() {
	ui.poll();
	ui.multiplex();
	if (ui.isSequencing()){
		run_sequence();
	}
//   disp.update();
//   disp.setDisplayAlpha("OPQ");
  
}

void run_sequence() {
	sequencer.updateClock();
	if (sequencer.stepWasIncremented()){
		ui.onStepIncremented();
	} 

}

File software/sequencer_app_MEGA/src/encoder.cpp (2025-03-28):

// #include "Variables.h"
#include "pinout.h"
#include "analogIO.h"
#include "encoder.h"
#include "display.h"
#include "calibrate.h"
#include "sequencer.h"
#include "Arduino.h"
#include <stdint.h>

#include <EEPROM.h>


int increment_amount = 0;
int encoder_amount = 0;

uint8_t pinA = 0xFF;
uint8_t pinB = 0xFF;
int8_t invert_encoder = 1;
const int encoder_invert_address = 16;

void Encoder::init(){
	pinMode(ENC_A_PIN, INPUT_PULLUP); //encoder A
	pinMode(ENC_B_PIN, INPUT_PULLUP); //encoder B
	invert_encoder = EEPROM.read(encoder_invert_address) > 0 ? -1 : 1;
}

//magic numbers from https://www.circuitsathome.com/mcu/reading-rotary-encoder-on-arduino/
int Encoder::poll(){
	///* returns change in encoder state (-1,0,1) */
	//int8_t read_encoder()
	//{
	increment_amount = 0;
	static int8_t enc_states[] = { 0,-1,1,0,1,0,0,-1,-1,0,0,1,0,1,-1,0 };
	static uint8_t old_AB = 0;
	/**/
	old_AB <<= 2;                   //remember previous state
	old_AB |= (ENC_PORT & 0x30) >> 4;  //add current state from pins A5 and A4, shifted to LSB
	encoder_increment(enc_states[(old_AB & 0x0f)]); //extract encrement/decrement value from state table
	return increment_amount * invert_encoder;
}

void Encoder::encoder_increment(int amt) {
	if (amt == 0) return;
	encoder_amount += amt;
	if (abs(encoder_amount) < 4) return; //encoder detent is too coarse for 1-per step granularity
	increment_amount = encoder_amount > 0 ? 1 : -1;
	encoder_amount = 0;
}

bool Encoder::toggle_inverted(){
	invert_encoder = invert_encoder * -1;
	EEPROM.write(encoder_invert_address, invert_encoder < 0 ? -1 : 0);
	return invert_encoder > 0;
}

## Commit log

2025-02-10 Edited PCB
    [sequencer-io.kicad_pcb, sequencer-io.kicad_sch]
2025-02-10 Added TCA8418
    [sequencer-io.kicad_pcb, sequencer-io.kicad_sch]
2025-02-11 Cleaned up schematic, added DAC and outputs
    [dac.kicad_sch, ios.kicad_sch, leds.kicad_sch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]
2025-02-11 Added gitignore
    [sequencer-io.kicad_pcb]
2025-02-11 lil update
    [dac.kicad_sch, ios.kicad_sch, leds.kicad_sch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]
2025-02-19 removed rp2040
    [sequencer-io.kicad_sch]
2025-02-25 complete overhaul
    [16-steps-B_Cu.gbr, 16-steps-B_Mask.gbr, 16-steps-B_Paste.gbr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]
2025-02-28 tidy up - remove duplicates
    [16-steps.kicad_pcb, 7-segment.step, dac.kicad_sch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]
2025-02-28 tidy up
    [16-steps-B_Cu.gbr, 16-steps-B_Mask.gbr, 16-steps-B_Paste.gbr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]
2025-03-07 clean up, added pdf schematics
    [16-steps-B_Cu.gbr, 16-steps-B_Mask.gbr, 16-steps-B_Paste.gbr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]
2025-03-09 added test sketch for 7 segment
    [16-steps-brd.dxf, 16-steps-simplified-brd.dxf]
2025-03-28 ported buttons.cpp and .h
2025-03-29 fixed font and character displaying function
    [Ui.cpp, display.cpp, main.cpp]
2025-03-30 corrected resistor values
    [7-segment.kicad_sch]
2025-03-30 fixed display init function
    [Ui.cpp, display.cpp, main.cpp]
2025-03-30 corrected pin assignments
